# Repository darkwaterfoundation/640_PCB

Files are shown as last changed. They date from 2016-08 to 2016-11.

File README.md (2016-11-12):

640 DC Motor driver
=======================

#License 

Designed by Dark Water Technologies. Distributed under a Creative Commons Attribution, Share-Alike license.
Development kits based on this product should be distributed under a similar license.
Commercial products using the 640 boards as a reference design need not comply with this license; further questions can be sent to team@darkwater.io.
Check license.txt for more information.

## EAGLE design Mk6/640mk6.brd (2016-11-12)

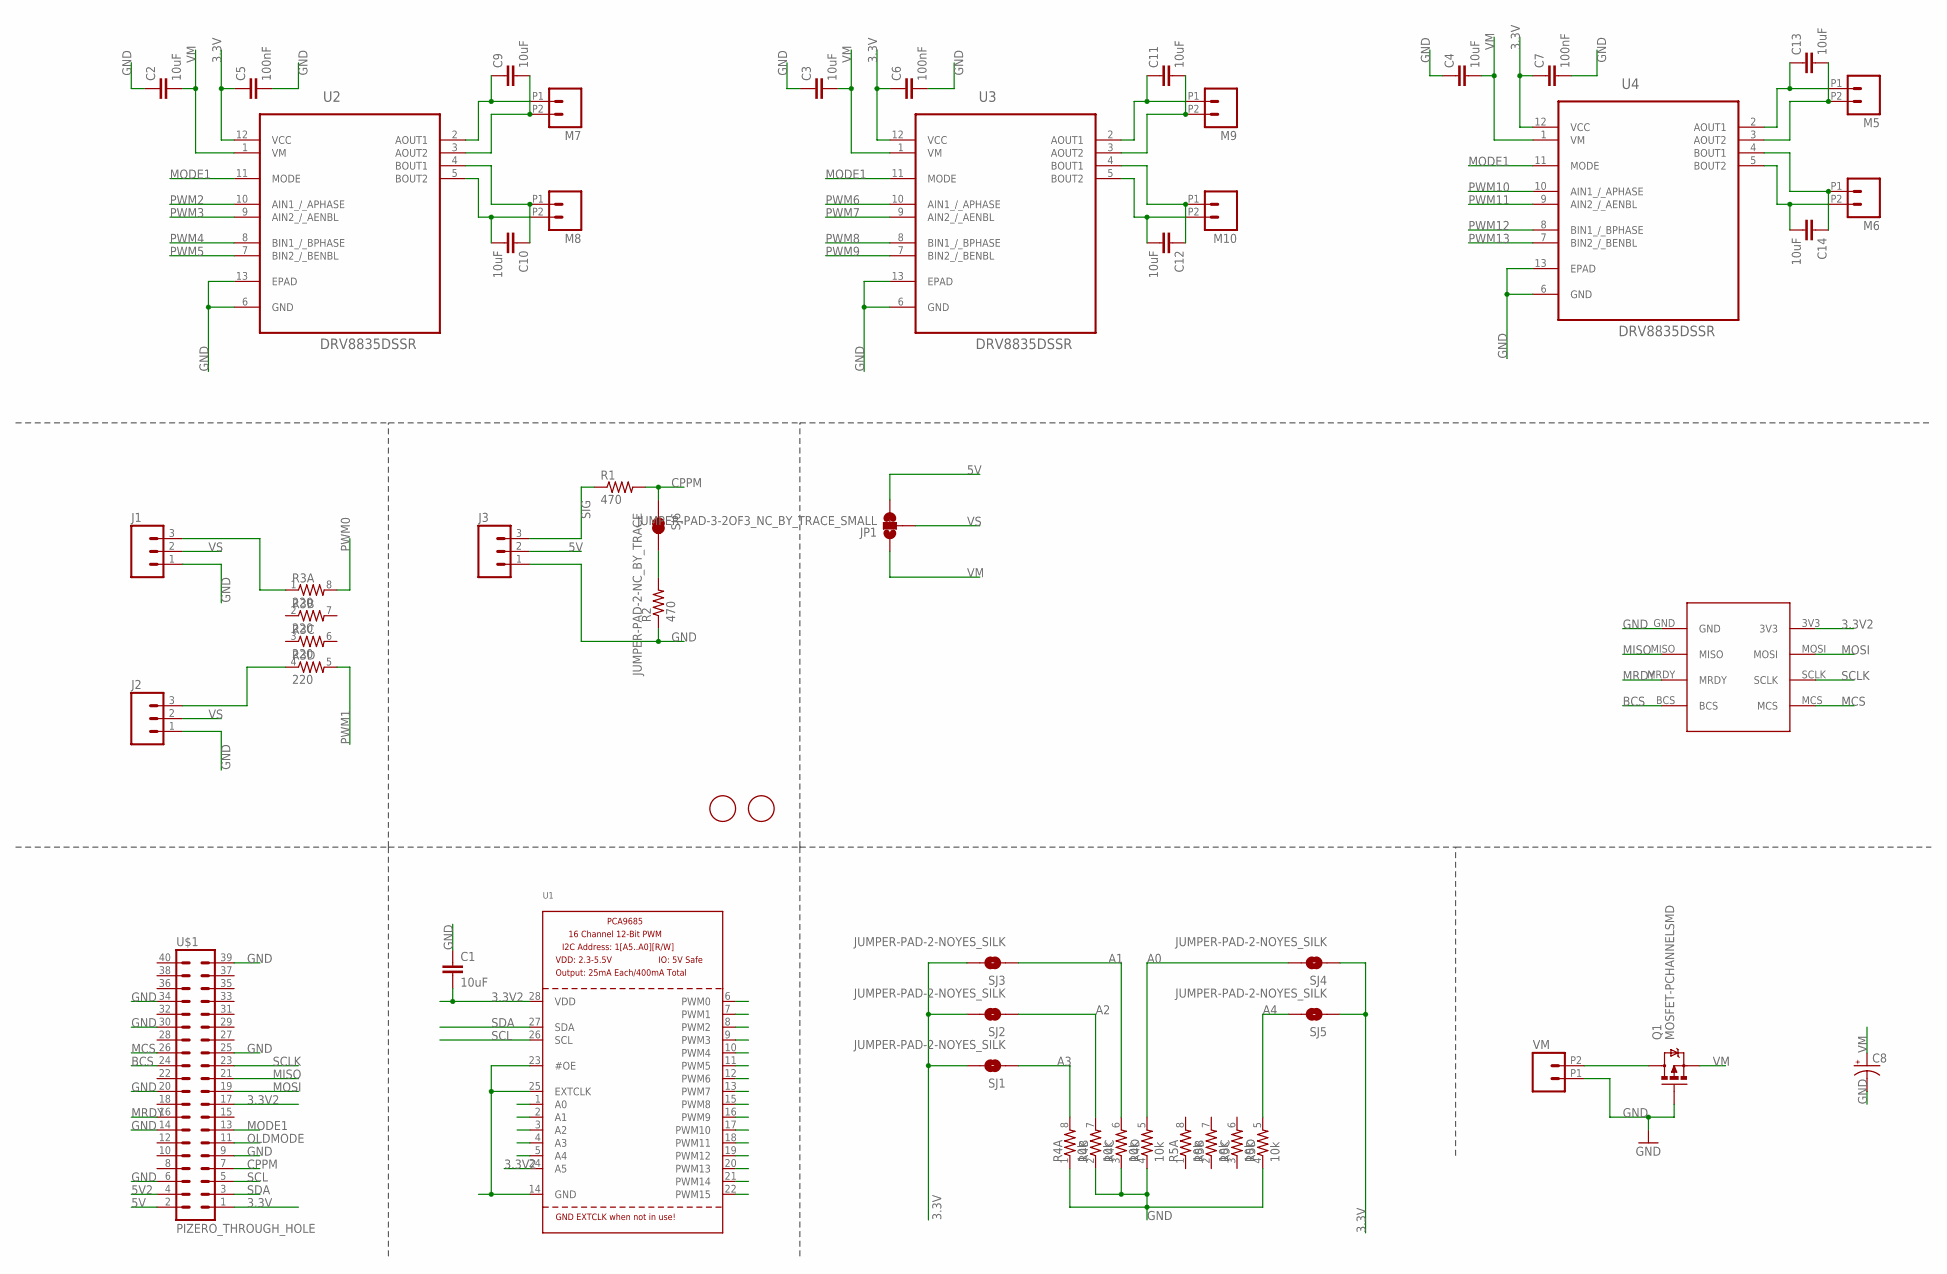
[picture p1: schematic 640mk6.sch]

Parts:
C1, C2, C3, C4, C9, C10, C11, C12, C13, C14: 10uF; 0805
C5, C6, C7: 100nF; 0805
C8: CAP_POLPTH1; CPOL-RADIAL-100UF-25V
FID1, FID2: FIDUCIAL; FIDUCIAL_1MM
J1, J2, J3: M03LOCK; 1X03_LOCK
JP1: JUMPER-PAD-3-2OF3_NC_BY_TRACE_SMALL; PAD-JUMPER-3-2OF3_NC_BY_TRACE_YES_SILK_FULL_BOX
M5, M6, M7, M8, M9, M10: M022.54MM_SCREWTERM; 1X02_2.54_SCREWTERM
Q1: MOSFET-PCHANNELSMD; SOT23-3
R1, R2: 470; 0805
R3: 220; 0603-ARV
R4, R5: 10k; 0603-ARV
SJ1, SJ2, SJ3, SJ4, SJ5: JUMPER-PAD-2-NOYES_SILK; PAD-JUMPER-2-NO_YES_SILK
SJ6: JUMPER-PAD-2-NC_BY_TRACE; PAD-JUMPER-2-NC_BY_TRACE_YES_SILK
U1: PCA9685; TSSOP28
U2, U3, U4: DRV8835DSSR; SON50P200X300X80-13N
U$1: PIZERO_THROUGH_HOLE; PIZERO_THOUGH_HOLE
U$2: 2X4PADS
VM: M022.54MM_SCREWTERM; 1X02_2.54_SCREWTERM

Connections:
3.3V: C5.1, C6.1, C7.1, SJ1.2, SJ2.2, SJ3.2, SJ4.1, SJ5.1, U2.12 (VCC), U3.12 (VCC), U4.12 (VCC), U$1.1
3.3V2: C1.2, U1.24 (A5), U1.28 (VDD), U$1.17, U$2.3V3
5V: J3.2, JP1.3, U$1.2
5V2: U$1.4
A0: R4.5 (2), SJ4.2, U1.1 (A0)
A1: R4.6 (2), SJ3.1, U1.2 (A1)
A2: R4.7 (2), SJ2.1, U1.3 (A2)
A3: R4.8 (2), SJ1.1, U1.4 (A3)
A4: R5.5 (2), SJ5.2, U1.5 (A4)
BCS: U$1.24, U$2.BCS
CPPM: R1.2, SJ6.1, U$1.7
GND: C1.1, C2.1, C3.1, C4.1, C5.2, C6.2, C7.2, C8.2 (-), J1.1, J2.1, J3.1, Q1.1 (G), R2.1, R4.1, R4.2 (1), R4.3 (1), R4.4 (1), R5.4 (1), U1.14 (GND), U1.23 (#OE), U1.25 (EXTCLK), U2.6 (GND), U2.13 (EPAD), U3.6 (GND), U3.13 (EPAD), U4.6 (GND), U4.13 (EPAD), U$1.6, U$1.9, U$1.14, U$1.20, U$1.25, U$1.30, U$1.34, U$1.39, U$2.GND, VM.P1 (1)
MCS: U$1.26, U$2.MCS
MISO: U$1.21, U$2.MISO
MODE1: U2.11 (MODE), U3.11 (MODE), U4.11 (MODE), U$1.13
MOSI: U$1.19, U$2.MOSI
MRDY: U$1.16, U$2.MRDY
unnamed: R2.2, SJ6.2
unnamed: J2.3, R3.4 (1)
unnamed: J1.3, R3.1
unnamed: Q1.3 (D), VM.P2 (2)
unnamed: C14.2, M6.P2 (2), U4.5 (BOUT2)
unnamed: C14.1, M6.P1 (1), U4.4 (BOUT1)
unnamed: C13.2, M5.P2 (2), U4.3 (AOUT2)
unnamed: C13.1, M5.P1 (1), U4.2 (AOUT1)
unnamed: C10.2, M8.P2 (2), U2.5 (BOUT2)
unnamed: C10.1, M8.P1 (1), U2.4 (BOUT1)
unnamed: C9.2, M7.P2 (2), U2.3 (AOUT2)
unnamed: C9.1, M7.P1 (1), U2.2 (AOUT1)
unnamed: C12.2, M10.P2 (2), U3.5 (BOUT2)
unnamed: C12.1, M10.P1 (1), U3.4 (BOUT1)
unnamed: C11.2, M9.P2 (2), U3.3 (AOUT2)
unnamed: C11.1, M9.P1 (1), U3.2 (AOUT1)
OLDMODE: U$1.11
PWM0: R3.8 (2), U1.6 (PWM0)
PWM1: R3.5 (2), U1.7 (PWM1)
PWM2: U1.8 (PWM2), U2.10 (AIN1_/_APHASE)
PWM3: U1.9 (PWM3), U2.9 (AIN2_/_AENBL)
PWM4: U1.10 (PWM4), U2.8 (BIN1_/_BPHASE)
PWM5: U1.11 (PWM5), U2.7 (BIN2_/_BENBL)
PWM6: U1.12 (PWM6), U3.10 (AIN1_/_APHASE)
PWM7: U1.13 (PWM7), U3.9 (AIN2_/_AENBL)
PWM8: U1.15 (PWM8), U3.8 (BIN1_/_BPHASE)
PWM9: U1.16 (PWM9), U3.7 (BIN2_/_BENBL)
PWM10: U1.17 (PWM10), U4.10 (AIN1_/_APHASE)
PWM11: U1.18 (PWM11), U4.9 (AIN2_/_AENBL)
PWM12: U1.19 (PWM12), U4.8 (BIN1_/_BPHASE)
PWM13: U1.20 (PWM13), U4.7 (BIN2_/_BENBL)
PWM14: U1.21 (PWM14)
PWM15: U1.22 (PWM15)
SCL: U1.26 (SCL), U$1.5
SCLK: U$1.23, U$2.SCLK
SDA: U1.27 (SDA), U$1.3
SIG: J3.3, R1.1
VM: C2.2, C3.2, C4.2, C8.1 (+), JP1.1, Q1.2 (S), U2.1 (VM), U3.1 (VM), U4.1 (VM)
VS: J1.2, J2.2, JP1.2

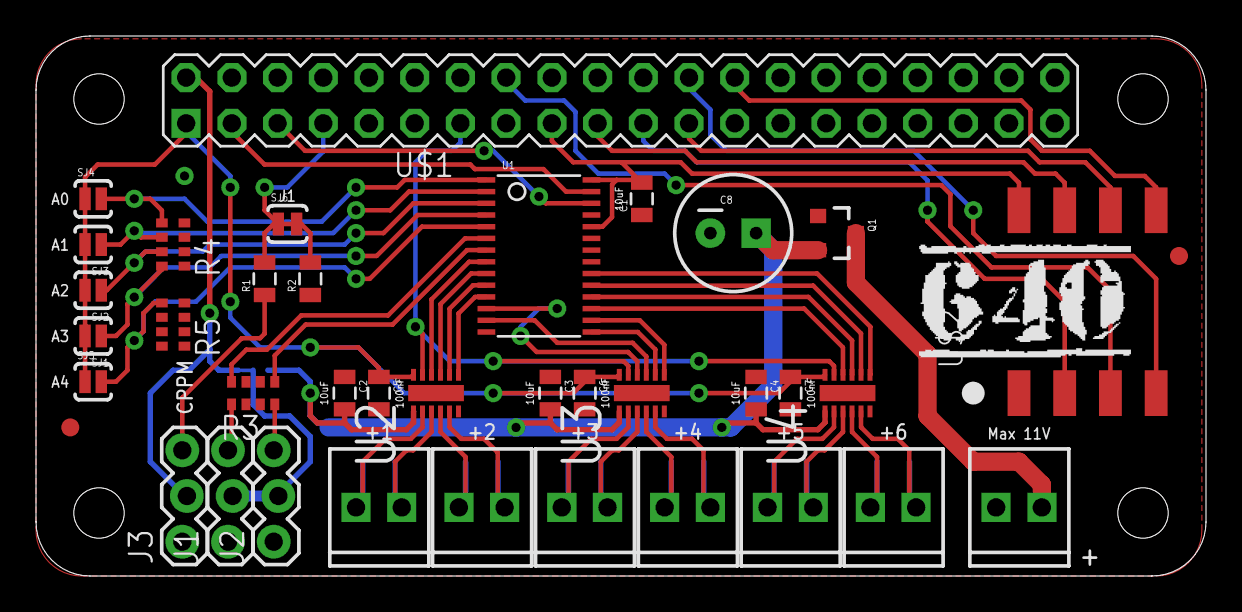
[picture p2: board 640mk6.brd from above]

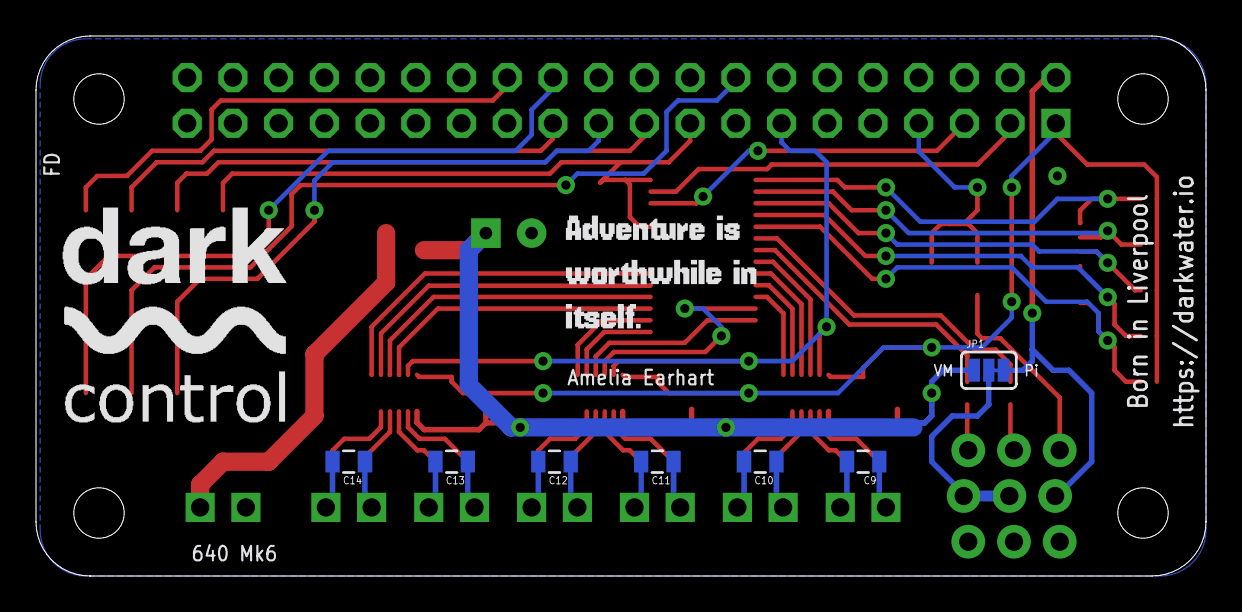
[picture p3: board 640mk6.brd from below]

Board: 2 copper layers, 65.0 x 30.0 mm, 48 parts (9 on the bottom side), 52 nets.

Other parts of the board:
U$3: DARKCONTROLSML
U$4: 640HORIZ
U$5: ADVENTURE

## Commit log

2016-08-13 Moved from other repository
    [640mk4.brd, 640mk4.sch]
2016-11-12 Added Mk6 designs
    [640mk6.brd, 640mk6.sch]

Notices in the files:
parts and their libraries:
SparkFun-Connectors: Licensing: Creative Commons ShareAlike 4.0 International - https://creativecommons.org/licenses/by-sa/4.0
